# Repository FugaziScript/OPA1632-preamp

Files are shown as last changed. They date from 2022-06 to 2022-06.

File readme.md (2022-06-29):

#OPA1632 preamp

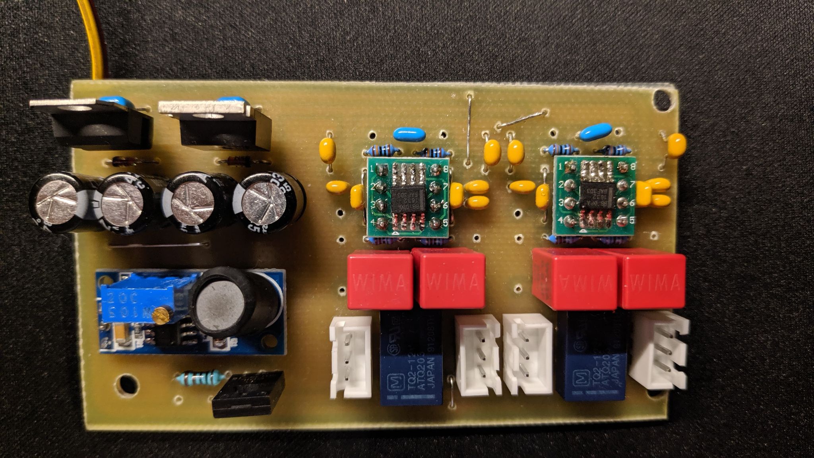
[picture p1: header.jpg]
Header Picture


przedwzmacniacz z 2 kanałami, sterowanymi przez przekaźniki. Na wyjściu jest sygnał symetryczny (potrzebny do wysterowania TPA3255). 
Na wejściu akceptowane są sygnały symetryczne, jaki i niesymetryczne. OPA1632 jest w stanie  symetryzować sygnał single-ended, jeżeli jedno z wejść jest dołączone do masy. Zasilanie układów jest z pojedyńczego +12V. Poprzez przetwornicę generującą napięcie ujemne oraz stabilizatory gwarantujące niskie szumy, nie ma potrzeby stosować kondensatorów na wyjściu OPA1632. Wzmocnienie układu wynosi 1. 
Płytka pcb jest bardzo ciasno upakowana, gdyż w obudowie nie było dużo miejsca (jest to największe pcb jakie się zmieściło). Wykonane w technologii tht ze względów na koszty oraz brak precyzji przy wytrawianiu płytki oraz lutowaniu elementów smd.

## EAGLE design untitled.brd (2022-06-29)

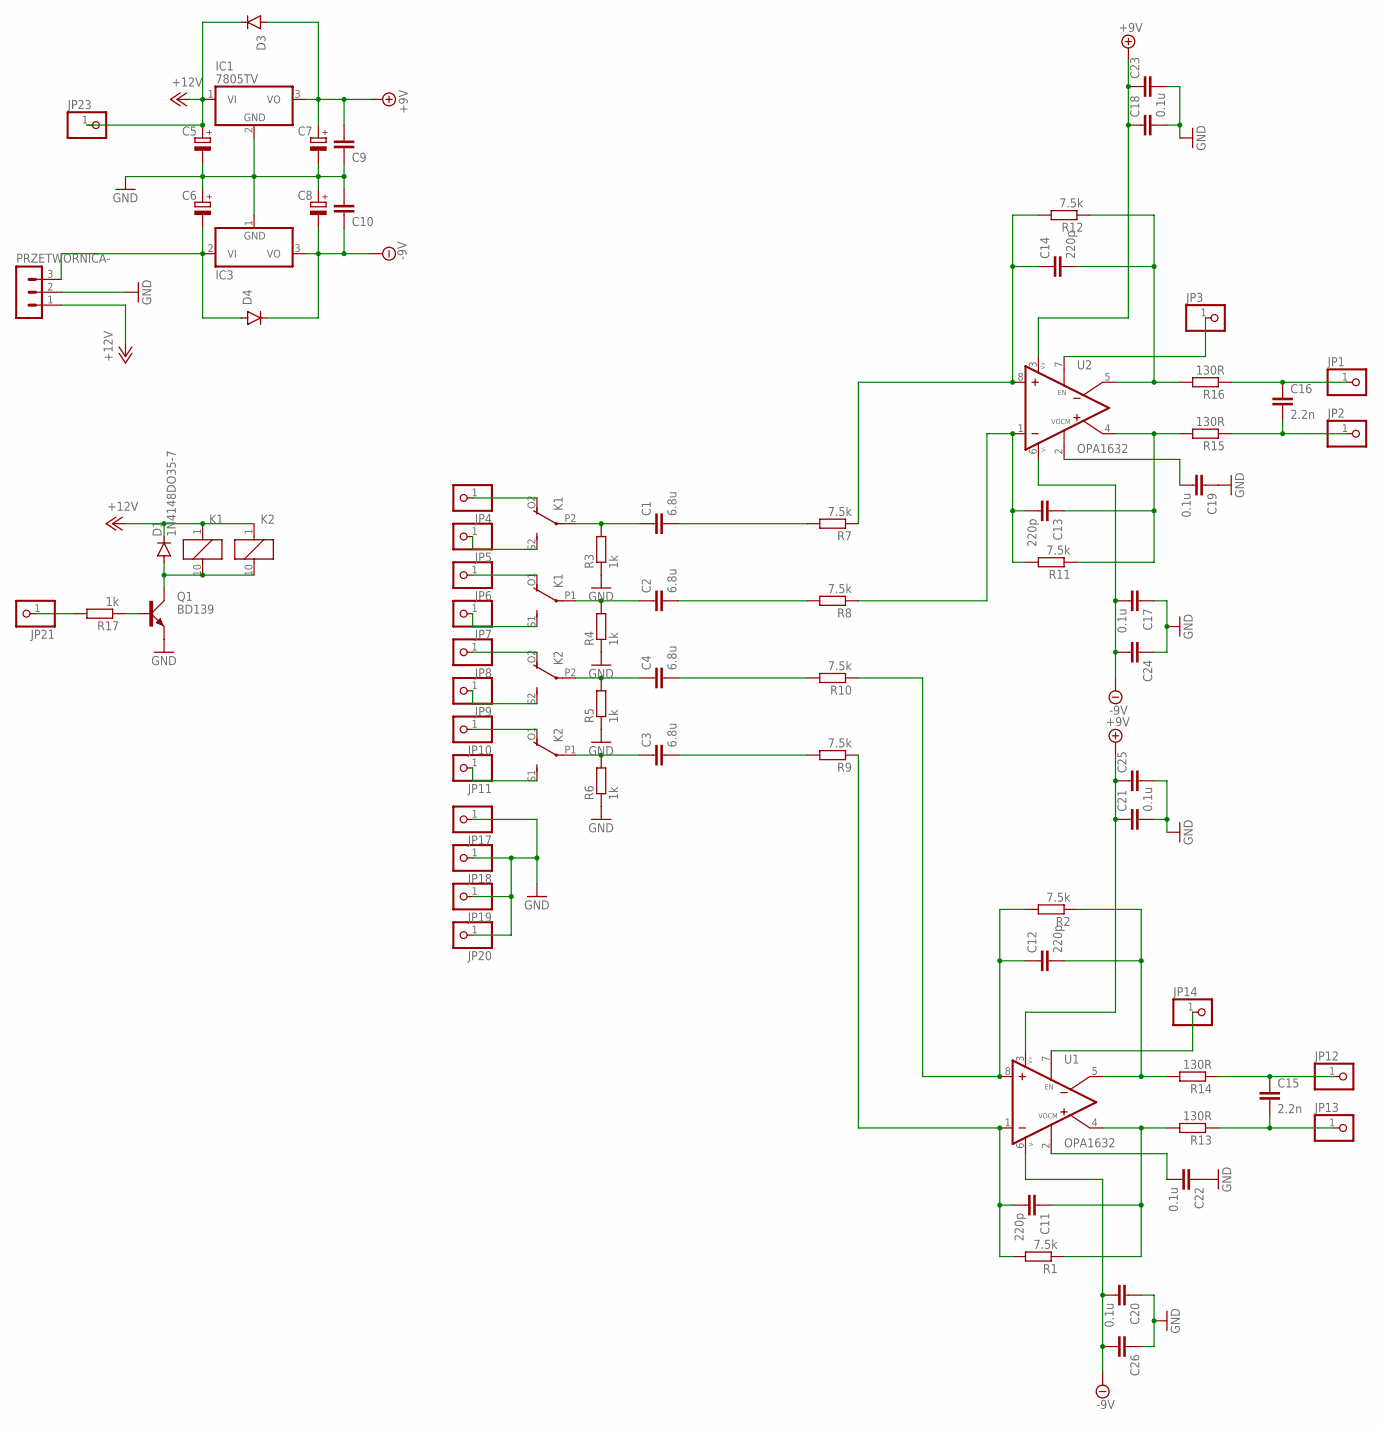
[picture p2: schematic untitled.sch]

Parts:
C1, C2, C3, C4: 6.8u; C5B7.2
C5, C6, C7, C8: CPOL-EUE3.5-8; E3,5-8
C9, C10, C23, C24, C25, C26: C-EU050-024X044; C050-024X044
C11, C12, C13, C14: 220p; C075-032X103
C15, C16: 2.2n; C025-024X044
C17, C18, C19, C20, C21, C22: 0.1u; C025-024X044
D1, D3, D4: 1N4148DO35-7; DO35-7
IC1: 7805TV; TO220V
IC3: 79; TO220V
JP1, JP2, JP3, JP4, JP5, JP6, JP7, JP8, JP9, JP10, JP11, JP12, JP13, JP14, JP17, JP18, JP19, JP20, JP21, JP23: PINHD-1X1; 1X01
K1, K2: G6H2-100
PRZETWORNICA-: MA03-1
Q1: BD139; TO126AV
R1, R2, R11, R12: 7.5k; 0204/7
R3, R4, R5, R6, R17: 1k; 0204/7
R7, R8, R9, R10: 7.5k; 0204/5
R13, R14, R15, R16: 130R; 0204/5
U1, U2: OPA1632; PRZEJSCIOWKA

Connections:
+9V: C7.+, C9.2, C18.1, C21.1, C23.1, C25.1, D3.A, IC1.3 (VO), U1.3 (V+), U2.3 (V+)
+12V: C5.+, D1.C, D3.C, IC1.1 (VI), JP23.1, K1.1, K2.1, PRZETWORNICA-.1
-9V: C8.-, C10.1, C17.2, C20.2, C24.2, C26.2, D4.C, IC3.3 (VO), U1.6 (V-), U2.6 (V-)
GND: C5.-, C6.+, C7.-, C8.+, C9.1, C10.2, C17.1, C18.2, C19.1, C20.1, C21.2, C22.1, C23.2, C24.1, C25.2, C26.1, IC1.2 (GND), IC3.1 (GND), JP17.1, JP18.1, JP19.1, JP20.1, PRZETWORNICA-.2, Q1.E, R3.1, R4.1, R5.1, R6.1
unnamed: JP4.1, K1.O2 (O)
unnamed: JP5.1, K1.S2 (S)
unnamed: JP6.1, K1.O1 (O)
unnamed: JP7.1, K1.S1 (S)
unnamed: D1.A, K1.10 (2), K2.10 (2), Q1.C
unnamed: JP10.1, K2.O1 (O)
unnamed: C12.1, R2.2, R10.1, U1.8 (+IN)
unnamed: Q1.B, R17.1
unnamed: JP9.1, K2.S2 (S)
unnamed: JP11.1, K2.S1 (S)
unnamed: JP8.1, K2.O2 (O)
unnamed: C3.2, R9.2
unnamed: C3.1, K2.P1, R6.2
unnamed: C4.1, K2.P2, R5.2
unnamed: C2.1, K1.P1, R4.2
unnamed: C1.1, K1.P2, R3.2
unnamed: C1.2, R7.2
unnamed: C2.2, R8.2
unnamed: C4.2, R10.2
unnamed: JP21.1, R17.2
unnamed: C14.1, R7.1, R12.2, U2.8 (+IN)
unnamed: C13.2, R8.1, R11.2, U2.1 (-IN)
unnamed: C11.2, R1.2, R9.1, U1.1 (-IN)
unnamed: C13.1, R11.1, R15.2, U2.4 (+OUT)
unnamed: C6.-, D4.A, IC3.2 (VI), PRZETWORNICA-.3
unnamed: C14.2, R12.1, R16.2, U2.5 (-OUT)
unnamed: C16.1, JP1.1, R16.1
unnamed: C16.2, JP2.1, R15.1
unnamed: C11.1, R1.1, R13.2, U1.4 (+OUT)
unnamed: C12.2, R2.1, R14.2, U1.5 (-OUT)
unnamed: C19.2, U2.2 (VOCM)
unnamed: JP3.1, U2.7 (EN)
unnamed: C15.1, JP12.1, R14.1
unnamed: C15.2, JP13.1, R13.1
unnamed: C22.2, U1.2 (VOCM)
unnamed: JP14.1, U1.7 (EN)

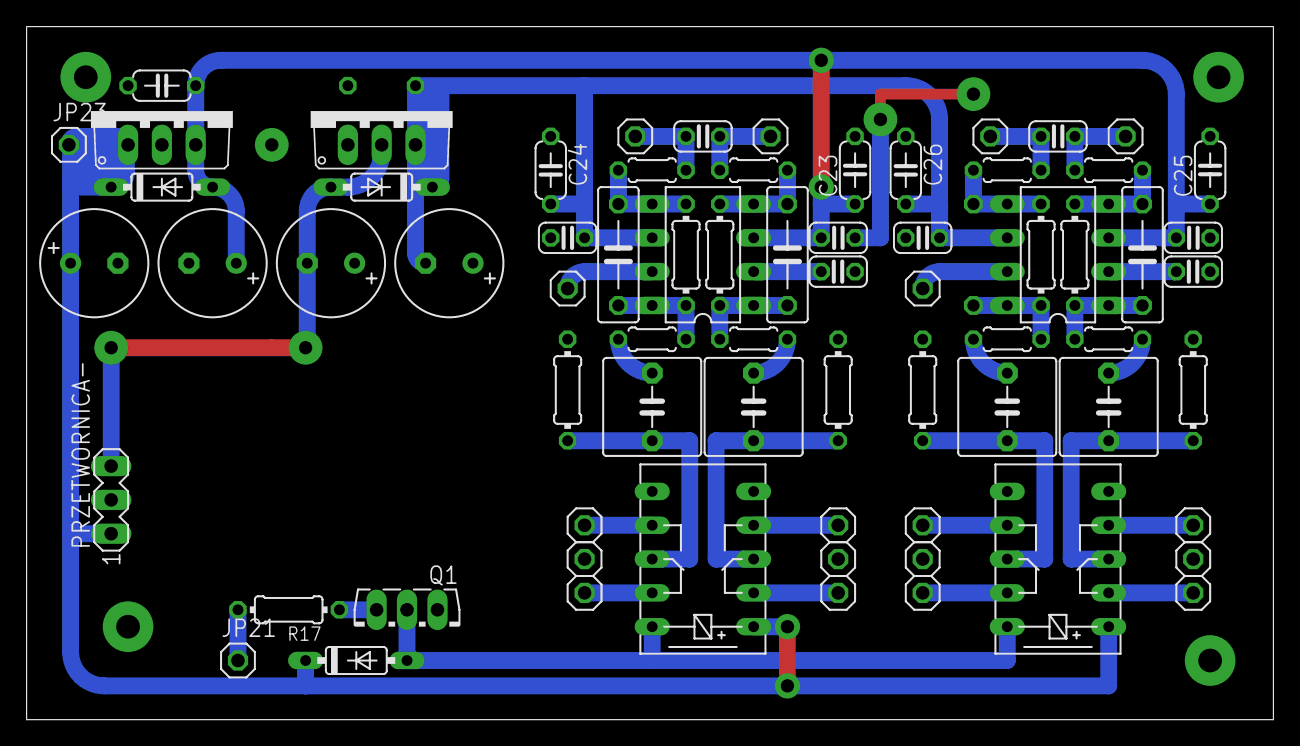
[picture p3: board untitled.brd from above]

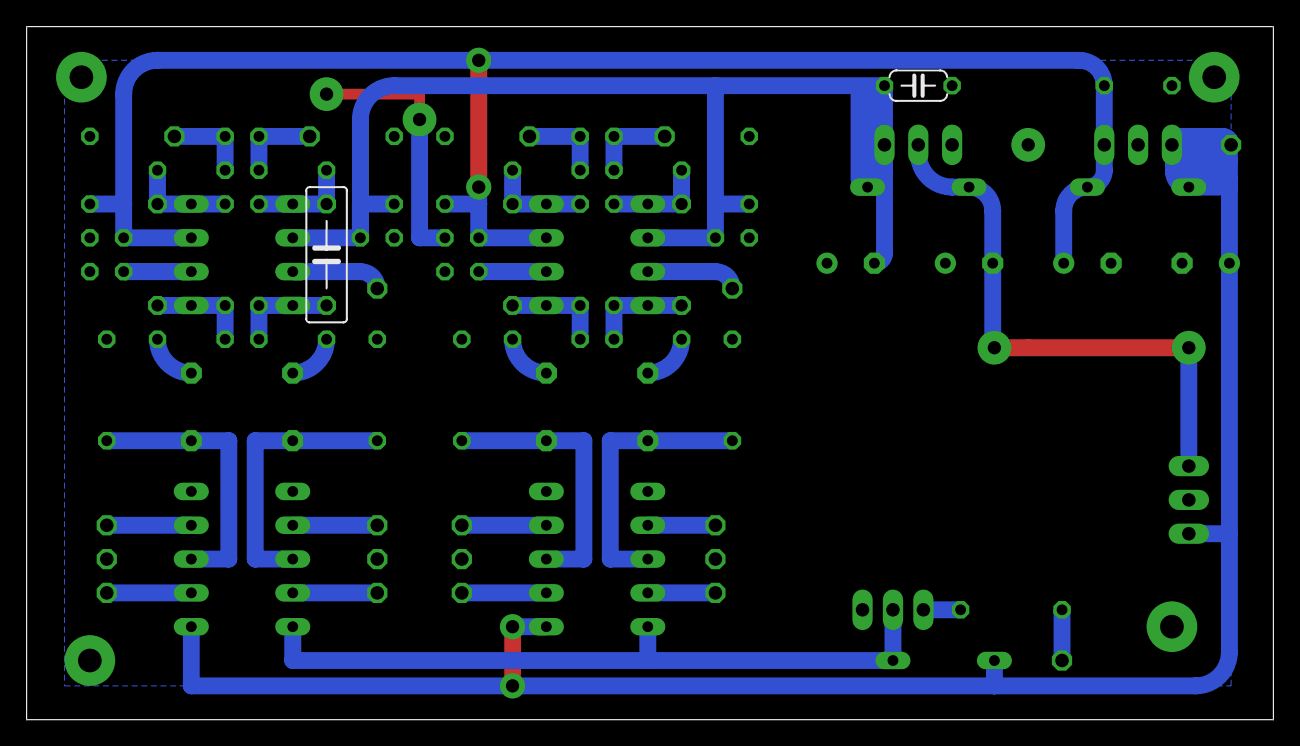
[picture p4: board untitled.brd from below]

Board: 2 copper layers, 93.6 x 52.1 mm, 74 parts (2 on the bottom side), 40 nets.
